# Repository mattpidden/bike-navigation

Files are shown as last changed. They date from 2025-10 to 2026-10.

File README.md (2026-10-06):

# Bike Navigation

A DIY bike computer: a 3D-printed, handlebar-mounted display (ESP32-S3 + round LCD) paired over Bluetooth to a phone app, showing a live, rendered map with your position and route — no phone screen required once you're riding.

<p align="center">
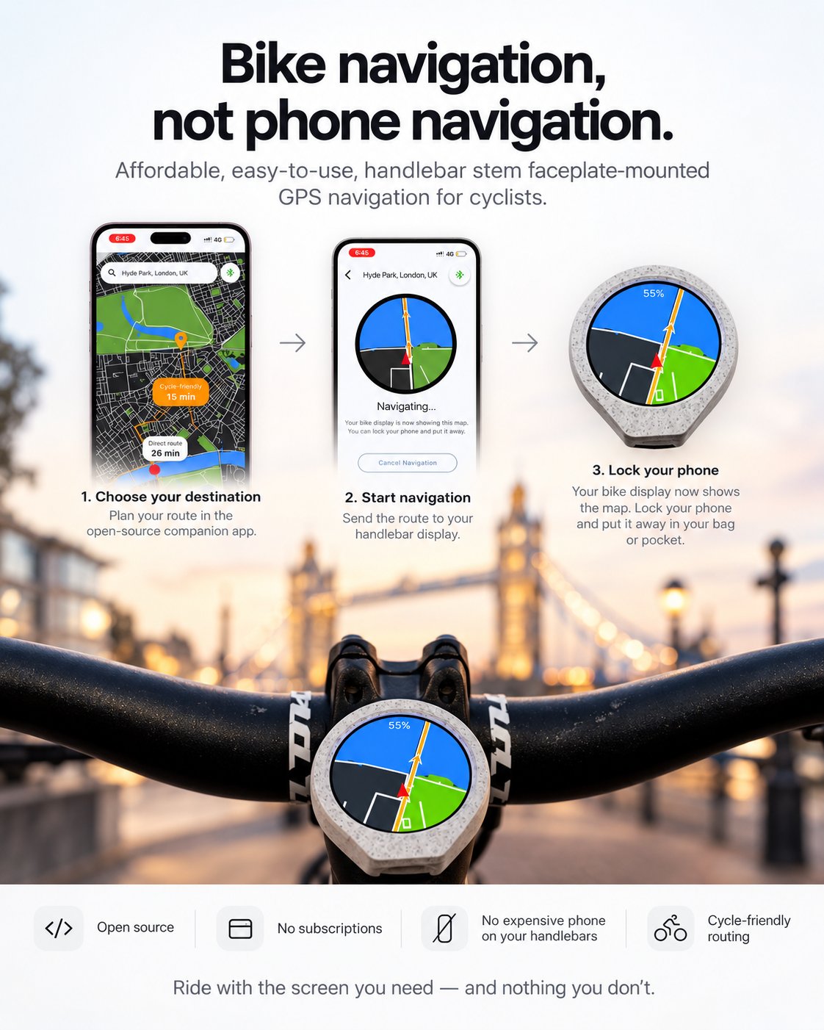
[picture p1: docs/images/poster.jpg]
Bike navigation, not phone navigation: choose a destination in the app, start navigation, then lock your phone while the handlebar display shows the map
  
<p align="center">
  Bike navigation, not phone navigation: choose a destination in the app, start navigation, then lock your phone while the handlebar display shows the map
</p>

## How it works

- **The app** (Flutter, Android/iOS) gets your GPS location and, when you pick a destination, a cycling route from Google Directions. It streams your position, heading, and route to the bike-mounted display over Bluetooth Low Energy.
- **The display** (ESP32-S3 + round LCD, twist-locked onto a stem faceplate mount) renders an offline vector map — roads, water, parks — baked into its own flash storage, and draws your live position/route on top of it. It doesn't need a network connection or GPS of its own; the phone supplies the data.
- **The display** (ESP32-S3 + round LCD, twist-locked onto a stem faceplate mount) renders an offline vector map — roads, water, parks — baked into its own flash storage, and draws your live position/route on top of it. It doesn't need a network connection or GPS of its own; the phone supplies the data.
- **The map data** for both the display and the app's own on-screen map comes from OpenStreetMap, processed by a small Python pipeline in `maps/` into a compact custom binary format.

<table>
  <tr>
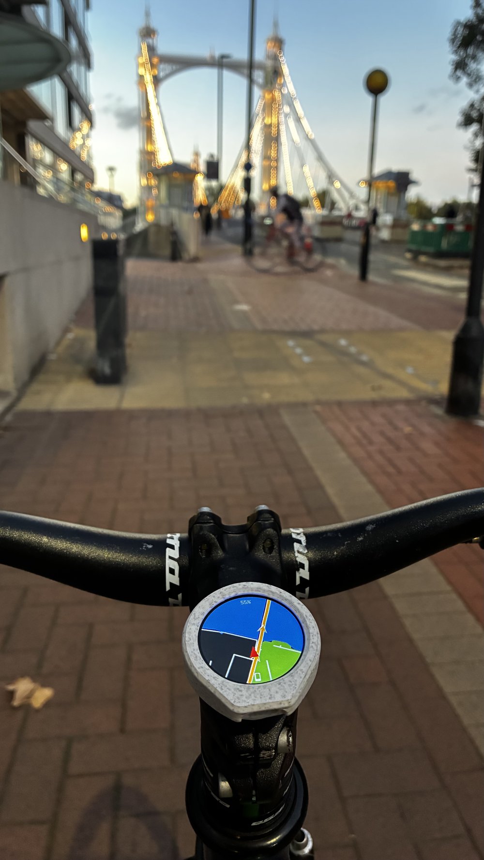
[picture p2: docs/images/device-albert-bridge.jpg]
The display mounted on a bike's stem, showing the map near Albert Bridge
    <td></td>
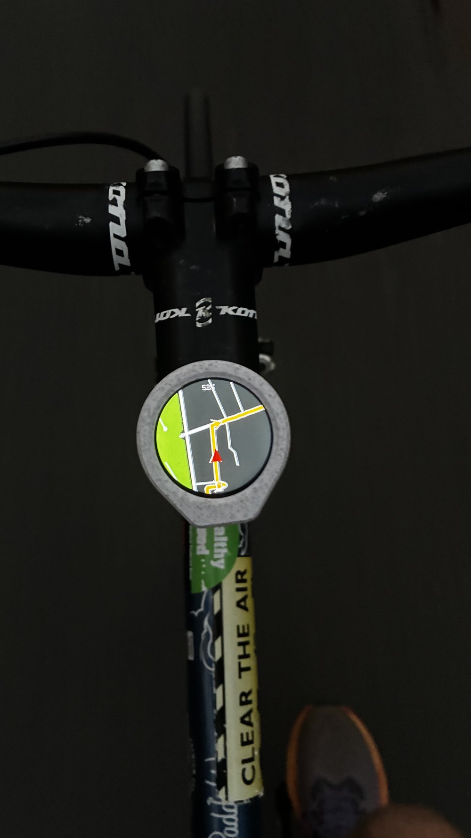
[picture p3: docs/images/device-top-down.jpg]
Top-down view of the display on the stem, mid-route
    <td></td>
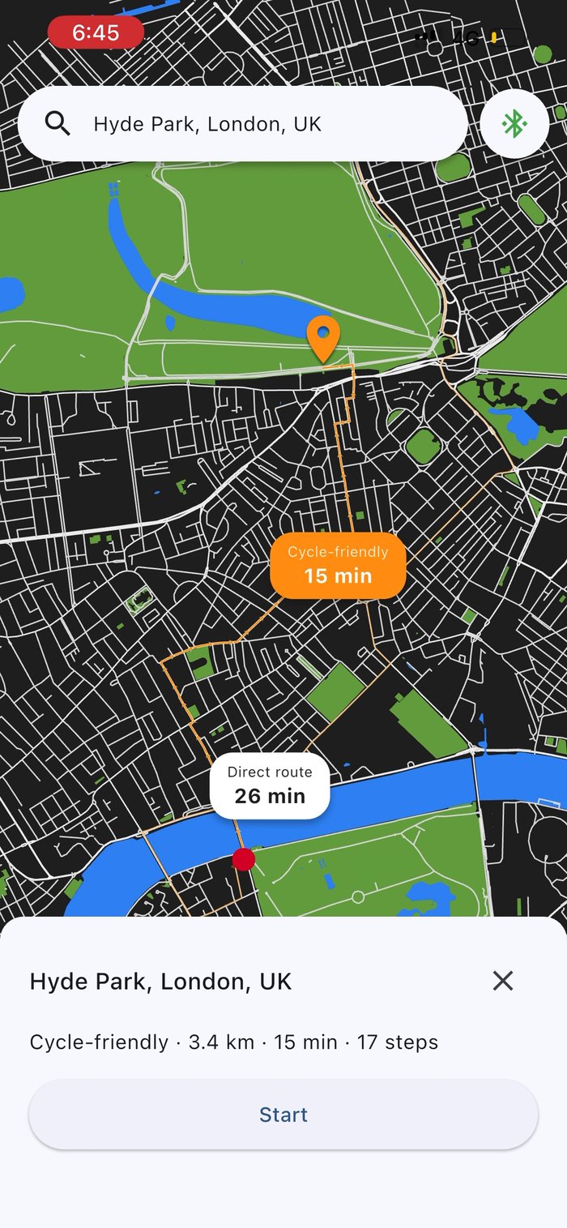
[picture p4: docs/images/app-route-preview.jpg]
App: route preview comparing cycle-friendly and direct routes
    <td></td>
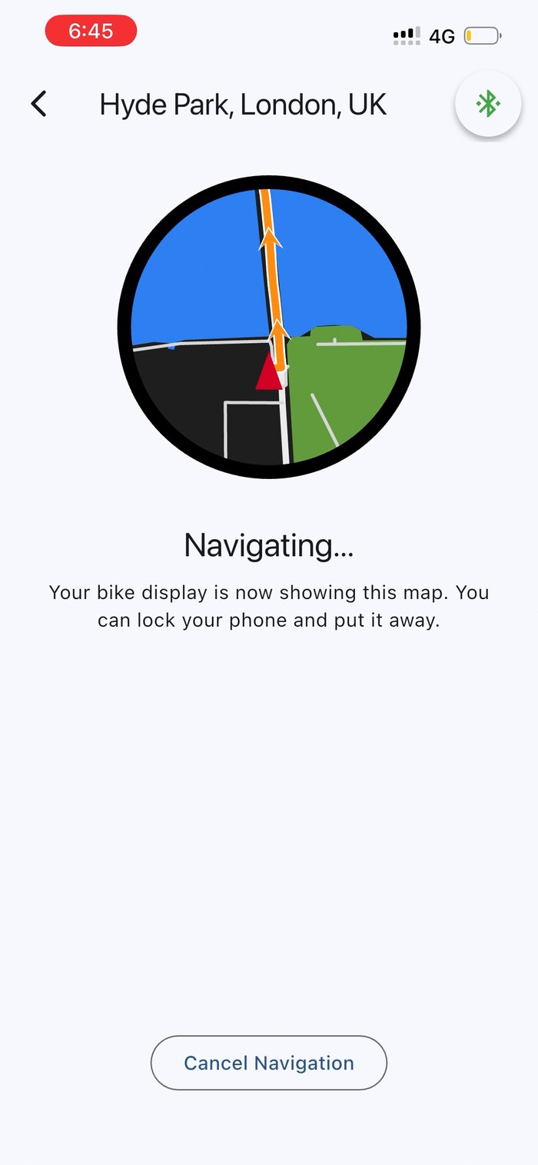
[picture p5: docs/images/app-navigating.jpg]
App: navigating screen mirroring what the bike display shows
    <td></td>
  </tr>
  <tr>
    <td align="center">On the bike</td>
    <td align="center">Mid-route</td>
    <td align="center">Choosing a route</td>
    <td align="center">Navigating</td>
  </tr>
</table>

## Build history

It didn't start out looking like the photos above.

<table>
  <tr>
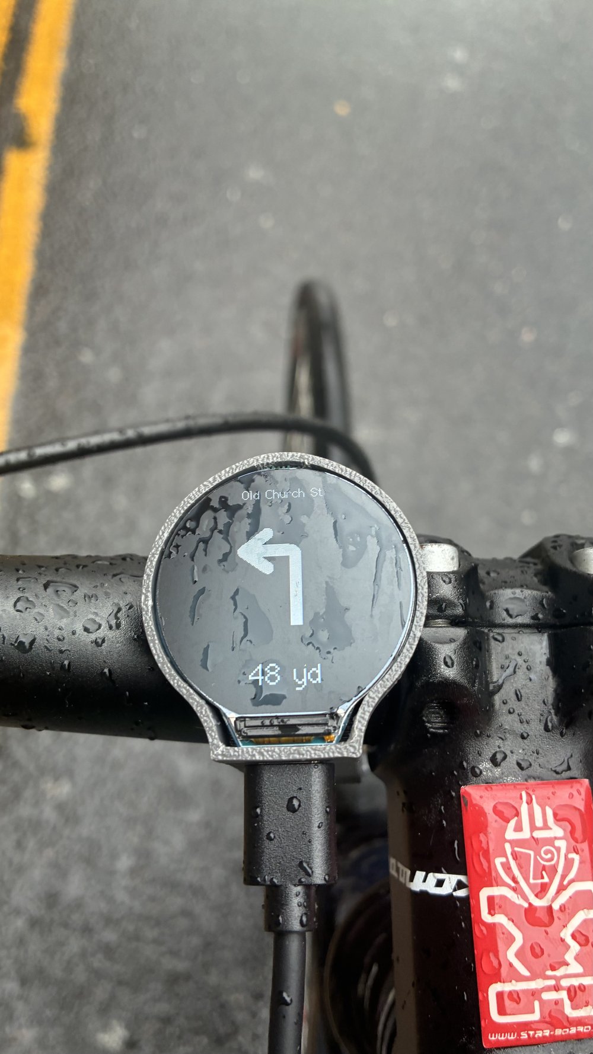
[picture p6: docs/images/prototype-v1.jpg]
V1 prototype: bare display in a rough case, powered over USB, showing a turn arrow and distance
    <td></td>
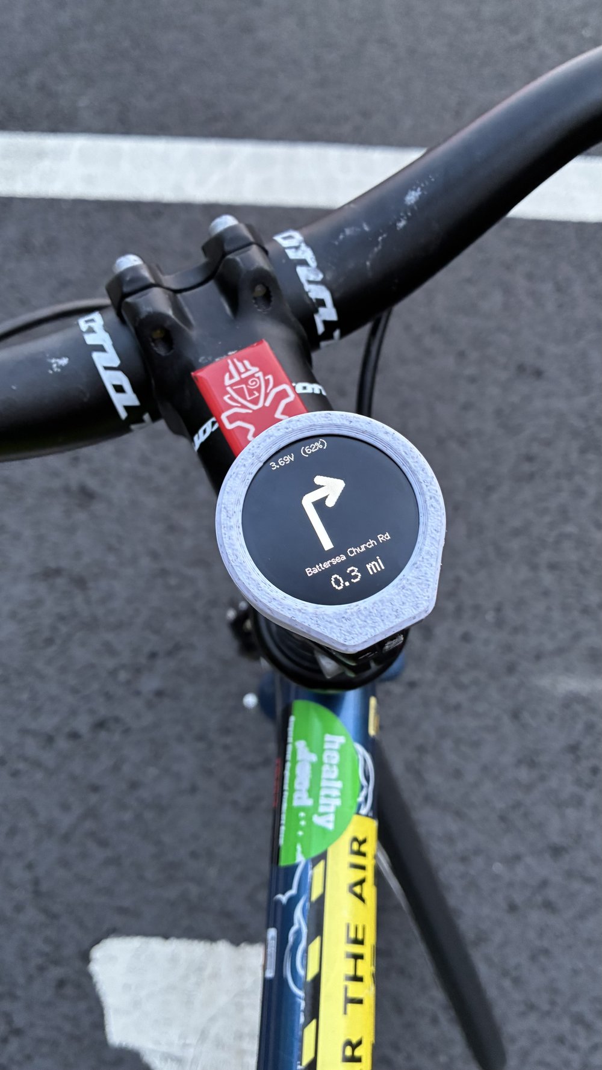
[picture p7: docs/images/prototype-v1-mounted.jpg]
V1 UI on the finished twist-lock mount, now battery-powered
    <td></td>
  </tr>
  <tr>
    <td align="center">V1</td>
    <td align="center">V1 UI, final mount + battery</td>
  </tr>
</table>

- **V1** had a poorly designed case and a bare-bones UI, but it worked: it paired with the app and showed turn-by-turn directions. It had no battery, so it ran off USB from a power bank.
- **Next came the hardware.** The twist-lock stem mount and an internal battery made it a self-contained unit, but the screen still showed only V1's basic turn arrow and distance.
- **The current version** replaced the arrows with the live, rendered map shown at the top of this README.

This is a hobby project, not a product — expect some rough edges, and treat the build instructions below as "this is how I did it," not a fully productised guide.

## Disclaimer

This is a hobbyist project, not a certified navigation or safety device. Route/map data can be wrong, outdated, or missing entirely, and Google's routing has no awareness of this project's hardware or your specific bike. Always use your own judgement: check a route before and while riding, don't follow it onto roads you shouldn't be cycling on (motorways, etc.), and obey local traffic laws regardless of what's on the screen. You use this project, and build/ride with it, entirely at your own risk — the author(s) accept no liability for any injury, damage, or other consequence arising from its use.

## Repo layout

```
app/       Flutter app (Android/iOS)
firmware/  ESP32-S3 firmware (Arduino)
maps/      OSM -> map.bin data pipeline + a pygame preview tool
cad/       3D-printable enclosure (STL files)
```

## Hardware

- [Waveshare ESP32-S3-Touch-LCD-1.28](https://www.waveshare.com/esp32-s3-touch-lcd-1.28.htm) — ESP32-S3 with a built-in 240×240 round GC9A01 LCD and QMI8658 IMU. This board's built-in battery-voltage ADC is used for the battery indicator; the IMU isn't currently used for anything (heading comes from the phone's GPS instead). ([buy](https://www.amazon.co.uk/dp/B0CSFFHNWT))
- A LiPo battery compatible with the board's JST connector. ([buy](https://www.amazon.co.uk/dp/B08215WQMQ))
- An on/off switch. These aren't commonly sold individually — the linked product is a multi-pack of assorted switches, of which you only need one. ([buy](https://www.amazon.co.uk/dp/B0817GD1Y8))
- The 3D-printed enclosure in `cad/`: `Concept Body` and `Concept Lid` house the electronics and twist-lock onto `Concept Mount`, which screws into the stem cap bolt in the center of your handlebars (the same mounting point Garmin/Wahoo-style quarter-turn bike computer mounts use). No particular print settings are prescribed — just make sure the LCD cutout, port openings, and the twist-lock tolerance line up with your printer before committing to a full print.

CAD design and enclosure by Tom Pidden.

## 1. Set up a Google Maps API key

The app uses Google's **Directions API** and **Places API** for routing and destination search.

1. Create a project in the [Google Cloud Console](https://console.cloud.google.com/).
2. Enable **Directions API** and **Places API** for that project (APIs & Services → Library).
3. Create an API key (APIs & Services → Credentials → Create Credentials → API key).
4. Set up billing on the project — Google requires a billing account even to stay within the free monthly credit.
5. **Set API restrictions** (Credentials → your key → API restrictions → Restrict key) to just **Directions API** and **Places API** — the only two this app calls. This limits the blast radius if the key ever leaks: it can only be used to call these two APIs, nothing else on your account.
6. **Application restrictions**: the app calls these APIs with plain HTTP requests (`http.get`) rather than through Google's native Android/iOS SDKs, so it doesn't send the package-name/cert headers that an "Android apps" or "iOS apps" restriction checks for — setting one would just break the app's requests. There isn't a clean restriction option for this key's actual usage pattern (a mobile app making direct REST calls); API restrictions above are your main protection. If you want tighter control, the real fix is routing these calls through your own backend and keeping the key server-side (restricted by IP) instead of embedding it in the app — this project doesn't do that today.

You'll use this key in step 3.

## 2. Flash the firmware

1. Install the [Arduino IDE](https://www.arduino.cc/en/software) and the ESP32 board support package (Boards Manager → search "esp32", install the Espressif package). Select an **ESP32S3 Dev Module** board profile with PSRAM enabled.
2. Install the [TFT_eSPI](https://github.com/Bodmer/TFT_eSPI) library (Library Manager → search "TFT_eSPI" by Bodmer) — this repo doesn't vendor it.
3. Point TFT_eSPI at this project's display config: copy `firmware/libaries/TFT_eSPI_Setups/Setup207_GC9A01.h` into the `User_Setups/` folder of your installed TFT_eSPI library, then edit that library's `User_Setup_Select.h` to `#include <User_Setups/Setup207_GC9A01.h>` instead of whatever's active by default. This file has the exact pin mapping for the Waveshare ESP32-S3-Touch-LCD-1.28's GC9A01 display.
4. Open `firmware/src/src.ino` in the Arduino IDE, select your board and port, and upload.
   - The baked map (`firmware/src/map_data.h`) already covers Central London out of the box (see step 4 below to build your own). If the sketch doesn't fit, try a "Huge APP" partition scheme (Tools → Partition Scheme).
5. On first boot the display shows "Waiting for GPS..." until the app connects and sends a location.

## 3. Build the app

1. Install [Flutter](https://docs.flutter.dev/get-started/install) and its Android/iOS toolchains.
2. `cd app && flutter pub get`
3. Copy `app/assets/.env.example` to `app/assets/.env` and fill in your API key from step 1:
   ```
   GOOGLE_MAPS_API_KEY=your_key_here
   ```
4. `flutter run` (with a device/emulator connected), or `flutter build apk` / `flutter build ios` for a release build.
5. `flutter test` runs the test suite.

**iOS only**: the bundle identifier and signing team in `app/ios/Runner.xcodeproj` are set to generic placeholders (`com.example.bikenavigation`, no team). Open `app/ios/Runner.xcworkspace` in Xcode and set your own bundle ID and Apple Developer Team under Runner → Signing & Capabilities before building for a real device — `flutter build ios`/`flutter run` on a device will fail without this. The Android build has no such step; it already ships with Flutter's generic `com.example.bike_navigation` and debug signing.

The app also bundles `maps/map.bin` directly (`pubspec.yaml` references it via a relative path outside `app/`) for its own on-screen map — no separate copy step needed, but it does mean `maps/map.bin` must exist (it's committed, covering Central London by default).

## 4. Building your own area's map (optional)

The repo ships with `maps/map.bin` pre-built for Central London. To cover your own area instead:

1. Download an OSM extract for your area from [BBBike's extract service](https://extract.bbbike.org/) in **`.osm.pbf`** format. A city-sized extract is plenty — this pipeline isn't built for anything continent-sized.
2. Put the downloaded file in `maps/`, and in `maps/build_map.py`, update:
   - `PBF` to point to your downloaded file.
   - `ORIGIN_LAT` / `ORIGIN_LON` to a point near the center of your area — everything is stored as meters relative to this point.
3. **Also update the matching origin constants in `app/lib/services/ble_protocol.dart`** (`originLat`/`originLon`) to the exact same values. The app projects GPS coordinates into this same local coordinate frame before sending them to the display — if the two origins don't match, your live position won't line up with the map.
4. Install [GDAL](https://gdal.org/) (provides the `ogr2ogr` command-line tool the pipeline shells out to) and Python 3.
5. `cd maps && python3 build_map.py` — this produces the new `map.bin`.
6. `python3 export_firmware.py` — converts `map.bin` into `firmware/src/map_data.h`; re-flash the firmware afterwards.
7. Optionally preview your map before flashing: `pip install pygame && python3 visualiser.py` opens an interactive pygame window at the same 240×240 geometry as the real display (WASD to move, Q/E to rotate, Z/X to zoom — see the script's docstring for the full control list). `python3 visualiser.py --snapshot out.png` renders one static frame without opening a window.

Note: the Thames polygon in the default map data comes from a separate, small OS OpenMap Local extract (`maps/thames_tidal_os.geojson`), not from OSM — the relevant OSM relation didn't reconstruct cleanly from a bbox-clipped extract. If your area includes a similarly large water body and OSM's polygon for it looks broken/missing in the visualiser, you may need to source an equivalent polygon yourself; `build_map.py`'s comments around `THAMES_TIDAL_GEOJSON` explain the shape it expects.

## Contributing

Issues and PRs are welcome. A few things worth knowing:

- There are effectively **three renderers of the same map data** that need to stay visually consistent: the firmware (`firmware/src/MapRenderer.h`, C++), the pygame preview (`maps/visualiser.py`, Python), and the app's own map view (`app/lib/widgets/offline_map_view.dart` and `app/lib/widgets/device_preview_map.dart`, Dart). If you change map styling (colors, widths, the route chevrons, etc.), it's worth checking whether the change should apply to all three.
- `maps/map_format.py` is the canonical spec/parser for the binary map format — start there if you need to understand or change the on-disk layout.
- The app has a real test suite (`app/test/`) covering the BLE protocol, route tracking, coordinate projection, and map parsing — `flutter test` before opening a PR.
- The Python pipeline has no test suite; the visualiser is the main way to sanity-check changes to it.

## License

[MIT](LICENSE) — covers the whole repo, including the CAD files.

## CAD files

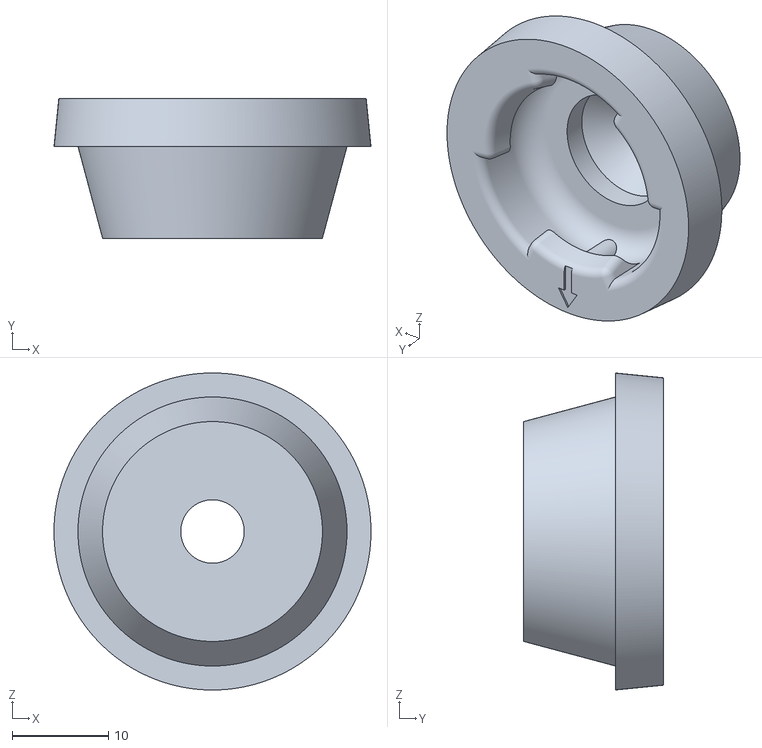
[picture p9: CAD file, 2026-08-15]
cad/0026 BPT_001-4-101125 - Concept Mount.STL
33.0 x 14.6 x 33.0

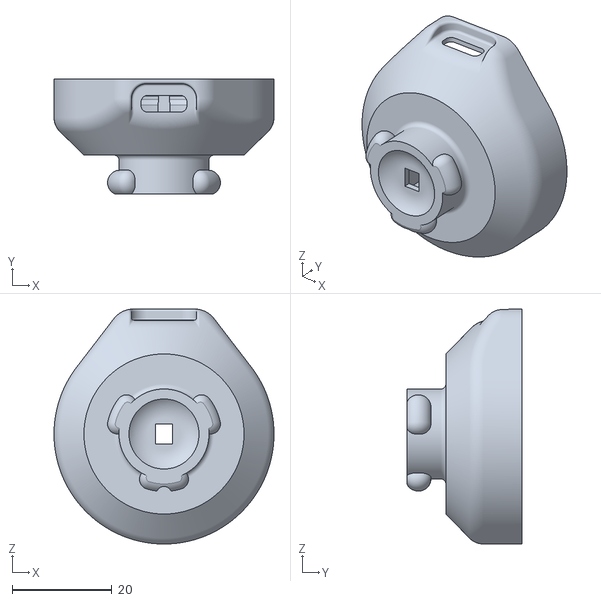
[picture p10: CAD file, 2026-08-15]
cad/0026 BPT_001-4-101125 - Concept Body.STL
44.0 x 23.1 x 47.0

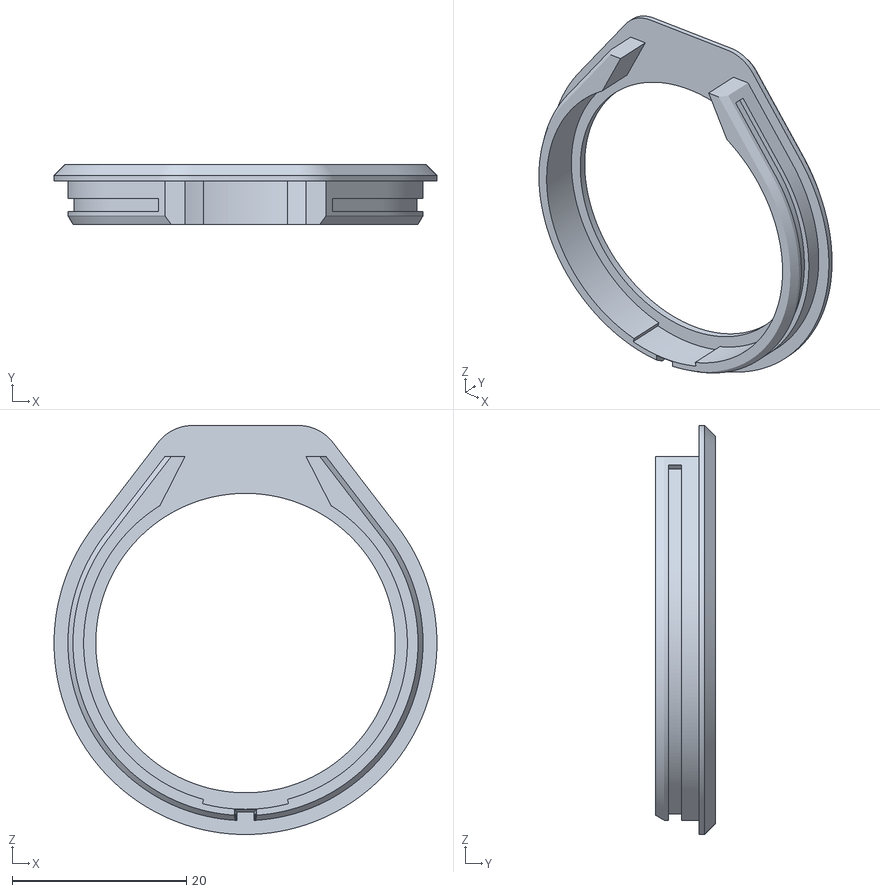
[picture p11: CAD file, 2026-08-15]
cad/0026 BPT_001-4-101125 - Concept Lid.STL
44.0 x 6.90 x 47.0

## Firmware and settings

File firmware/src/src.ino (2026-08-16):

/*
  This sketch demonstrates the use of the horizontal and vertical gradient
  rectangle fill functions.

  Example for library:
  https://github.com/Bodmer/TFT_eSPI

  Created by Bodmer 27/1/22
*/
#include "QMI8658.h"
#include <TFT_eSPI.h>       // Include the graphics library
#include <BLEDevice.h>
#include <BLEServer.h>
#include <BLEUtils.h>
#include "MapRenderer.h"


// Global variables
TFT_eSPI tft = TFT_eSPI();  // Create object "tft"
TFT_eSprite frame = TFT_eSprite(&tft);
bool deviceConnected = false;
enum AppState {
  STATE_HOME,
  STATE_NAVIGATION,
  STATE_ARRIVED
};
AppState currentState = STATE_HOME;

// Live telemetry from the phone (BLE TELEMETRY packets) — meters relative to the
// same home origin as the baked map data; frozen at last-known value on disconnect
// rather than reset, since a glanced-at wearable benefits from "last known view"
// over a blank one.
float currentPosX = 0, currentPosY = 0;
float currentHeadingDeg = 0;
bool telemetryReceived = false;

// Live route overlay (BLE ROUTE_START/ROUTE_CHUNK/ROUTE_END/ROUTE_CLEAR) — session
// data, not baked map data, so it lives in RAM as a fixed-size buffer rather than
// flash. "build" fills up as chunks arrive; ROUTE_END atomically swaps it into
// "active" so a route is never drawn mid-transfer.
#define ROUTE_MAX_POINTS 400
RoutePoint routeBuildBuf[ROUTE_MAX_POINTS];
RoutePoint routeActiveBuf[ROUTE_MAX_POINTS];
uint16_t routeBuildCount = 0;
uint16_t routeActiveCount = 0;
bool routeReady = false;

// Phone Icon
const unsigned char ble_bitmap [] PROGMEM = {
  // '191, 20x20px
  0x07, 0xfe, 0x00, 0x0f, 0x0f, 0x00, 0x0c, 0x03, 0x00, 0x0c, 0x01, 0x00, 0x0c, 0x01, 0x00, 0x0c, 
  0x01, 0x00, 0x0c, 0x01, 0x00, 0x0c, 0x01, 0x00, 0x0c, 0x01, 0x00, 0x0c, 0x01, 0x00, 0x0c, 0x01, 
  0x00, 0x0c, 0x01, 0x00, 0x0c, 0x01, 0x00, 0x0c, 0x01, 0x00, 0x0c, 0x01, 0x00, 0x0f, 0xff, 0x00, 
  0x0f, 0xff, 0x00, 0x0f, 0x9f, 0x00, 0x0f, 0xff, 0x00, 0x07, 0xfe, 0x00
};

String batteryStatus;
unsigned long lastWriteTime = 0;
BLEServer* pServer;

class ServerCallbacks : public BLEServerCallbacks {
  void onConnect(BLEServer* pServer) {
    Serial.print("Connected to phone...");
    lastWriteTime = millis();
    deviceConnected = true;
  }
  void onDisconnect(BLEServer* pServer) {
    Serial.print("Disconnected...");
    pServer->startAdvertising();
    deviceConnected = false;
  }
};


// Binary BLE protocol (little-endian, matches ESP32/Xtensa native order — no byte
// swapping needed). First byte of every write is the packet type:
//   0x01 TELEMETRY   {x_cm:i32, y_cm:i32, heading_decideg:i16, mode:u8}      12B
//   0x02 ROUTE_START {total_points:u16}                                      3B
//   0x03 ROUTE_CHUNK {seq:u16, count:u8, (x_cm:i32,y_cm:i32)*count}      4+8*count B
//   0x04 ROUTE_END   {}                                                      1B
//   0x05 ROUTE_CLEAR {}                                                      1B
// Positions are centimeters relative to the same home-origin local frame the
// baked map data uses (see maps/build_map.py) — converted to meters on receipt.
class MyCallbacks : public BLECharacteristicCallbacks {
  void onWrite(BLECharacteristic *pCharacteristic) override {
    lastWriteTime = millis();
    String value = pCharacteristic->getValue();
    size_t len = value.length();
    if (len < 1) return;
    const uint8_t* d = (const uint8_t*)value.c_str();
    uint8_t type = d[0];

    switch (type) {
      case 0x01: {  // TELEMETRY
        if (len != 12) {
          Serial.println("TELEMETRY: bad length, dropping");
          break;
        }
        int32_t xCm, yCm;
        int16_t headingDd;
        memcpy(&xCm, d + 1, 4);
        memcpy(&yCm, d + 5, 4);
        memcpy(&headingDd, d + 9, 2);
        uint8_t mode = d[11];

        currentPosX = xCm / 100.0f;
        currentPosY = yCm / 100.0f;
        currentHeadingDeg = headingDd / 10.0f;
        telemetryReceived = true;

        switch (mode) {
          case 0: currentState = STATE_HOME; break;
          case 1: currentState = STATE_NAVIGATION; break;
          case 2: currentState = STATE_ARRIVED; break;
          default:
            Serial.println("TELEMETRY: unknown mode, defaulting to home");
            currentState = STATE_HOME;
        }
        break;
      }

      case 0x02: {  // ROUTE_START — reset the build buffer; active route stays visible
        if (len != 3) {
          Serial.println("ROUTE_START: bad length, dropping");
          break;
        }
        routeBuildCount = 0;
        break;
      }

      case 0x03: {  // ROUTE_CHUNK
        if (len < 4) {
          Serial.println("ROUTE_CHUNK: bad length, dropping");
          break;
        }
        uint8_t count = d[3];
        if (len != (size_t)(4 + count * 8)) {
          Serial.println("ROUTE_CHUNK: length mismatch, dropping");
          break;
        }
        for (uint8_t i = 0; i < count && routeBuildCount < ROUTE_MAX_POINTS; i++) {
          int32_t xCm, yCm;
          memcpy(&xCm, d + 4 + i * 8, 4);
          memcpy(&yCm, d + 4 + i * 8 + 4, 4);
          routeBuildBuf[routeBuildCount].x = xCm / 100.0f;
          routeBuildBuf[routeBuildCount].y = yCm / 100.0f;
          routeBuildCount++;
        }
        break;
      }

      case 0x04: {  // ROUTE_END — atomic swap so a half-received route is never drawn
        memcpy(routeActiveBuf, routeBuildBuf, routeBuildCount * sizeof(RoutePoint));
        routeActiveCount = routeBuildCount;
        routeReady = (routeActiveCount >= 2);
        break;
      }

      case 0x05: {  // ROUTE_CLEAR
        routeActiveCount = 0;
        routeBuildCount = 0;
        routeReady = false;
        break;
      }

      default:
        Serial.print("Unknown BLE packet type: ");
        Serial.println(type);
    }
  }
};

void setupBLE() {
  BLEDevice::init("ESP32");
  BLEDevice::setMTU(517);  // request the max ATT MTU — default (~20B usable) would make ROUTE_CHUNK transfer crawl
  pServer = BLEDevice::createServer();
  pServer->setCallbacks(new ServerCallbacks());

  BLEService *pService = pServer->createService("12345678-1234-1234-1234-1234567890ab");
  BLECharacteristic *pCharacteristic = pService->createCharacteristic(
      "87654321-4321-4321-4321-ba0987654321",
      BLECharacteristic::PROPERTY_WRITE | BLECharacteristic::PROPERTY_WRITE_NR | BLECharacteristic::PROPERTY_READ);
  pCharacteristic->setCallbacks(new MyCallbacks());

  pService->start();

  BLEAdvertising *pAdvertising = BLEDevice::getAdvertising();
  pAdvertising->addServiceUUID(pService->getUUID());
  pAdvertising->setScanResponse(true);
  pAdvertising->setMinPreferred(0x06);
  pAdvertising->setMaxPreferred(0x12);
  pAdvertising->start();

  Serial.println("BLE ready.");
}

void drawCenteredText(String text, int y, int textsize, uint16_t color = TFT_WHITE) {
  frame.setTextColor(color);
  frame.setTextFont(2);
  frame.setTextSize(textsize);
  int16_t h = frame.fontHeight();
  int16_t w = frame.textWidth(text);
  frame.setCursor((240 - w) / 2, y - (h / 2));
  frame.print(text);
}


// -------------------------------------------------------------------------
// Setup
// -------------------------------------------------------------------------
void setup(void) {
  Serial.begin(115200);
  delay(5000);
  Serial.println("Board On!");
  Wire.begin(6, 7);   // SDA=6, SCL=7
  delay(200);
  QMI8658_init();      // starts IMU
  Serial.println("IMU On");
  tft.init();
  tft.setRotation(0);
  tft.fillScreen(COLOR_BG);
  Serial.println("Screen On!");
  frame.createSprite(240, 240);
  setupBLE();
  lastWriteTime = millis();
}


// -------------------------------------------------------------------------
// Main loop
// -------------------------------------------------------------------------
const float MAP_VIEW_RADIUS_M = 150.0f;

// The map is the universal screen now — STATE_NAVIGATION/STATE_ARRIVED just change
// what's overlaid on top of it (route, "ARRIVED" text) rather than swapping to a
// separate screen, so BLE-icon/battery drawing isn't duplicated three times.
void drawHomeScreen() {
  frame.fillSprite(COLOR_BG);

  if (!telemetryReceived) {
    drawMap(frame, 0, 0, 0, MAP_VIEW_RADIUS_M, nullptr, 0, false);
    drawCenteredText("Waiting for GPS...", 120, 1);
  } else {
    drawMap(frame, currentPosX, currentPosY, currentHeadingDeg, MAP_VIEW_RADIUS_M,
            routeReady ? routeActiveBuf : nullptr, routeReady ? routeActiveCount : 0, true);
    if (currentState == STATE_ARRIVED) {
      drawCenteredText("ARRIVED", 120, 2, COLOR_RED);
    }
  }

  if (deviceConnected) {
    frame.drawBitmap(110, 215, ble_bitmap, 20, 20, TFT_WHITE);
  } else if (telemetryReceived) {
    drawCenteredText("Reconnecting...", 225, 1);
  }
  drawCenteredText(batteryStatus, 15, 1);
  frame.pushSprite(0, 0);
}

static unsigned long lastBatteryUpdate = 0;

void loop() {
  if (deviceConnected && millis() - lastWriteTime > 10000) {
    Serial.println("No write received for 10s — disconnecting client");
    pServer->disconnect(pServer->getConnId());
    deviceConnected = false;
  }
  if (millis() - lastBatteryUpdate >= 1000) {  // every 1 second
    lastBatteryUpdate = millis();
    uint16_t result = DEC_ADC_Read();
    const float conversion_factor = 3.3f / 4095.0f * 3.8f;
    float voltage = result * conversion_factor;
    float percent = (voltage - 3.0f) / (4.1f - 3.0f) * 100.0f;
    percent = constrain(percent, 0.0f, 100.0f);
    batteryStatus = String(percent, 0) + "%";
    Serial.println(batteryStatus);
  }
  // deviceConnected or not, currentState HOME/NAVIGATION/ARRIVED or not — it's
  // always the same map screen now, driven by whatever telemetry/route we last got.
  drawHomeScreen();
}

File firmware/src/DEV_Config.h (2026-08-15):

/*****************************************************************************
* | File      	:   DEV_Config.h
* | Author      :
* | Function    :   Hardware underlying interface
* | Info        :
*----------------
* |	This version:   V1.0
* | Date        :   2021-03-16
* | Info        :
#
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
# THE SOFTWARE IS PROVIDED "AS IS", WITHOUT WARRANTY OF ANY KIND, EXPRESS OR
# IMPLIED, INCLUDING BUT NOT LIMITED TO THE WARRANTIES OF MERCHANTABILITY,
# FITNESS OR A PARTICULAR PURPOSE AND NONINFRINGEMENT. IN NO EVENT SHALL THE
# AUTHORS OR COPYRIGHT HOLDERS BE LIABLE FOR ANY CLAIM, DAMAGES OR OTHER
# LIABILITY WHETHER IN AN ACTION OF CONTRACT, TORT OR OTHERWISE, ARISING FROM,
# OUT OF OR IN CONNECTION WITH THE SOFTWARE OR THE USE OR OTHER DEALINGS IN
# THE SOFTWARE.
******************************************************************************/
#ifndef _DEV_CONFIG_H_
#define _DEV_CONFIG_H_

#include "stdio.h"

#include <Arduino.h>
#include <SPI.h>
#include <Wire.h>
#include "Debug.h"
/**
 * data
 **/
#define UBYTE uint8_t
#define UWORD uint16_t
#define UDOUBLE uint32_t

#define SPI_PORT spi1
#define I2C_PORT i2c0

#if CONFIG_IDF_TARGET_ESP32S2 || CONFIG_IDF_TARGET_ESP32S3
#define VSPI FSPI
#endif

/**
 * GPIOI config
 **/

#define LCD_DC_PIN      (8)
#define LCD_CS_PIN      (9)
#define LCD_CLK_PIN     (10)
#define LCD_MOSI_PIN    (11)
#define LCD_MISO_PIN    (-1)
#define LCD_RST_PIN     (12)
#define LCD_BL_PIN      (40)

#define DEV_SDA_PIN     (6)
#define DEV_SCL_PIN     (7)

#define BAT_ADC_PIN     (1)

/*------------------------------------------------------------------------------------------------------*/

void DEV_Digital_Write(uint16_t Pin, uint8_t Value);
uint8_t DEV_Digital_Read(uint16_t Pin);

void DEV_GPIO_Mode(uint16_t Pin, uint16_t Mode);
void DEV_KEY_Config(uint16_t Pin);
void DEV_Digital_Write(uint16_t Pin, uint8_t Value);
uint8_t DEV_Digital_Read(uint16_t Pin);

uint16_t DEC_ADC_Read(void);

void DEV_SPI_WriteByte(uint8_t Value);
void DEV_SPI_Write_nByte(uint8_t *pData, uint32_t Len);

void DEV_Delay_ms(uint32_t xms);
void DEV_Delay_us(uint32_t xus);

void DEV_I2C_Write_Byte(uint8_t addr, uint8_t reg, uint8_t Value);
void DEV_I2C_Write_nByte(uint8_t addr, uint8_t *pData, uint32_t Len);
void DEV_I2C_Write_Register(uint8_t addr,uint8_t reg, uint16_t value);

uint8_t DEV_I2C_Read_Byte(uint8_t addr, uint8_t reg);
void DEV_I2C_Read_Register(uint8_t addr,uint8_t reg, uint16_t *value);
void DEV_I2C_Read_nByte(uint8_t addr, uint8_t reg, uint8_t *pData, uint32_t Len);

void DEV_SET_Backlight(uint8_t Value);

uint8_t DEV_Module_Init(void);
void DEV_Module_Exit(void);

#endif

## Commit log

2025-10-30 added CAD
    [0026 BPT_001-2-301025 - Concept BOTTOM.STL, 0026 BPT_001-2-301025 - Concept MOUNT.STL, 0026 BPT_001-2-301025 - Concept TOP.STL]
2025-11-11 added code to read battery %
    [0026 BPT_001-2-301025 - Concept BOTTOM.STL, 0026 BPT_001-2-301025 - Concept MOUNT.STL, 0026 BPT_001-2-301025 - Concept TOP.STL]
2025-11-11 updated CAD tweaks
    [0026 BPT_001-2-301025 - Concept BOTTOM.STL, 0026 BPT_001-2-301025 - Concept MOUNT.STL, 0026 BPT_001-2-301025 - Concept TOP.STL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]
2026-08-16 redesigned mobile app + firmware bug fixes
    [MapRenderer.h, src.ino]
2026-08-16 added full flow into app
2026-08-16 Clean repo for open-sourcing: stop tracking build artifacts and secrets
    Removes from tracking (kept locally, now gitignored): IDE/OS junk (.idea,
    .DS_Store), generated Flutter files (.dart_tool, .flutter-plugins*),
    platform build caches (app/android/.gradle, app/ios/Pods,
    app/ios/.symlinks, ephemeral/ dirs), Android local.properties and gradle
    wrapper binaries, the vendored TFT_eSPI Arduino library (our own hardware
    config in firmware/libaries/TFT_eSPI_Setups/ is kept), and regeneratable
    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
2026-08-16 Add a real README covering hardware, firmware, app, and map-pipeline setup
    Replaces the default Flutter-generated app/README.md boilerplate with a
    pointer to the root README, which now covers: what the project is, getting
    a Google Maps API key, flashing the firmware (including the TFT_eSPI setup
    this repo no longer vendors), building the app, and regenerating map.bin
    for a different area — plus a couple of things worth knowing before
    contributing (the three renderers that need to stay in sync, the test
    suite).
2026-08-16 README: add hardware purchase links and CAD credit; gitignore local Claude settings
2026-08-16 README: label the battery and on/off switch purchase links
2026-08-16 README: correct wearable -> handlebar-mounted, describe the mount, add disclaimer
    The device twist-locks onto a mount that screws into the stem cap bolt,
    not worn — fixes wording throughout. Also adds a safety/liability
    disclaimer: hobbyist project, not a certified nav device, use your own
    judgement on the road.
2026-08-16 Move map origin off a residential address, onto Battersea Park
    The origin was precise enough to pinpoint a specific house. Moves it
    ~1km to Battersea Park's coordinates instead — a public landmark, still
    well within the existing OSM extract's bounds, so the map's actual
    coverage is unaffected (same 20559 ways / 834 polygons). Regenerates
    map.bin and firmware/src/map_data.h from the new origin, and recomputes
    ble_protocol_test.dart's hardcoded reference values (which were the
    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
2026-08-16 README: clarify API restrictions and correct Application restrictions guidance
    Explicitly names which two APIs to restrict the key to. Also corrects the
    Application restrictions guidance — this app calls the REST endpoints via
    plain HTTP, not Google's native SDKs, so an Android/iOS app restriction
    would reject its requests (no package/cert headers to check). Notes the
    actual mitigation (API restrictions) and the real fix (server-side proxy)
    this project doesn't currently implement.
2026-10-06 README: add poster, device photos, and app screenshots
